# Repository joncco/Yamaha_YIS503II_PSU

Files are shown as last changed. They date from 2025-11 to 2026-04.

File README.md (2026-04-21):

# Universal Vintage Computer Power Supply
Idea for a "universal" power supply, either internal external, for different systems that require multiple input voltages (like 8080-based systems, or the BBC Model B).<br>

It's nothing groundbreaking, unique or even clever - it just uses off-the-shelf integrated components to generate the additional voltages.<br>

Expects regulated +12VDC input (rated at ≥5A).<br>

Passes through the +12VDC (≥400mA depending on input supply) and additionally outputs:
- Regulated +5VDC (max. 4A)
- Regulated -12VDC (max. 80mA)
- Regulated -5VDC (max. 500mA)

If the additional voltages are not required then they can be excluded from the build.<br>

Prevents reverse-polarity source input with a MOSFET (can be excluded if not required).<br>

The PCB measures 70x50mm and has M3 mounting holes in the corners (offset 42 & 62mm).<br>

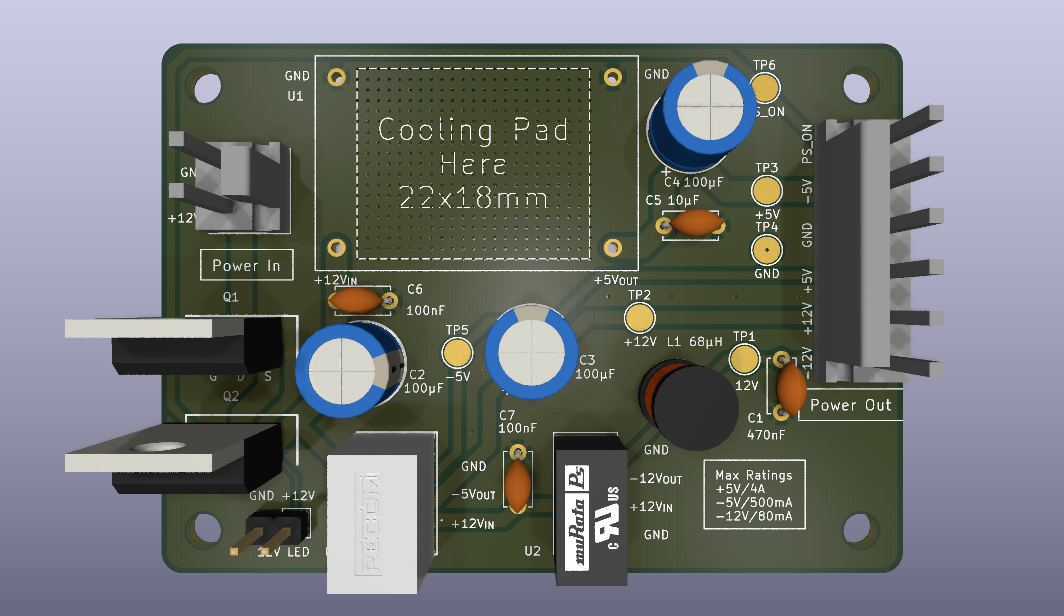
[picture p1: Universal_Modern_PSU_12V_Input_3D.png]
3D image of PCB


## [Data Sheets](/Datasheets)
Relevant data sheets to save you hunting around for the parts or trying to figure out replacements.

## [KiCad & Fabrication Files](/Universal_Modern_PSU_12V_Input)
KiCad 10 design files plus fabrication (Gerber) files

## Status
21-Nov-2025: Still tweaking the design before getting test boards made - current design should work but would like to improve further if possible

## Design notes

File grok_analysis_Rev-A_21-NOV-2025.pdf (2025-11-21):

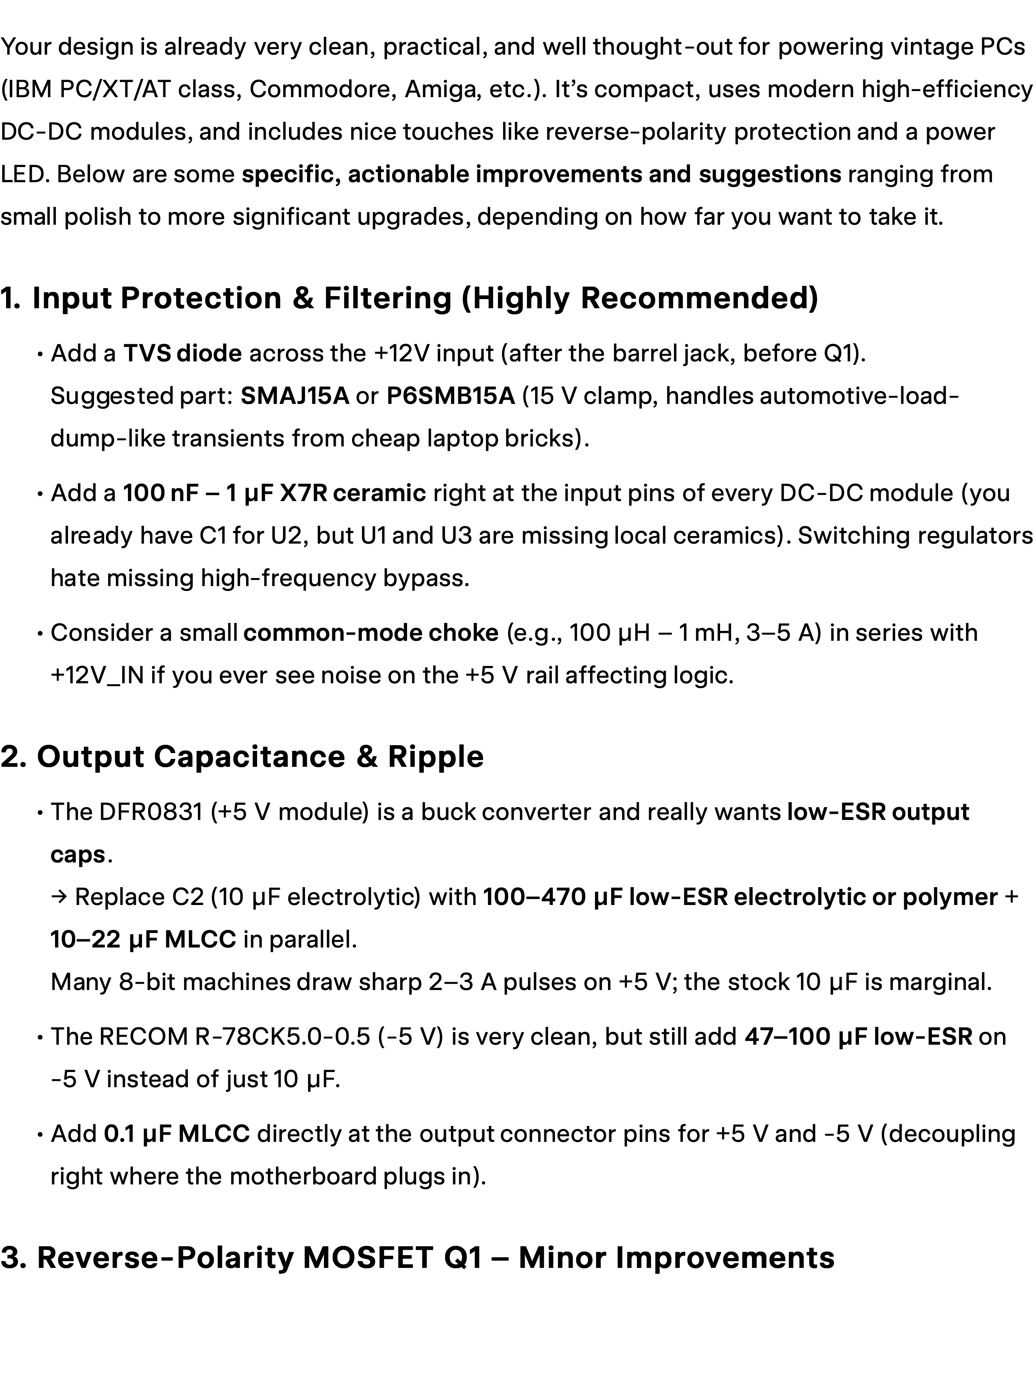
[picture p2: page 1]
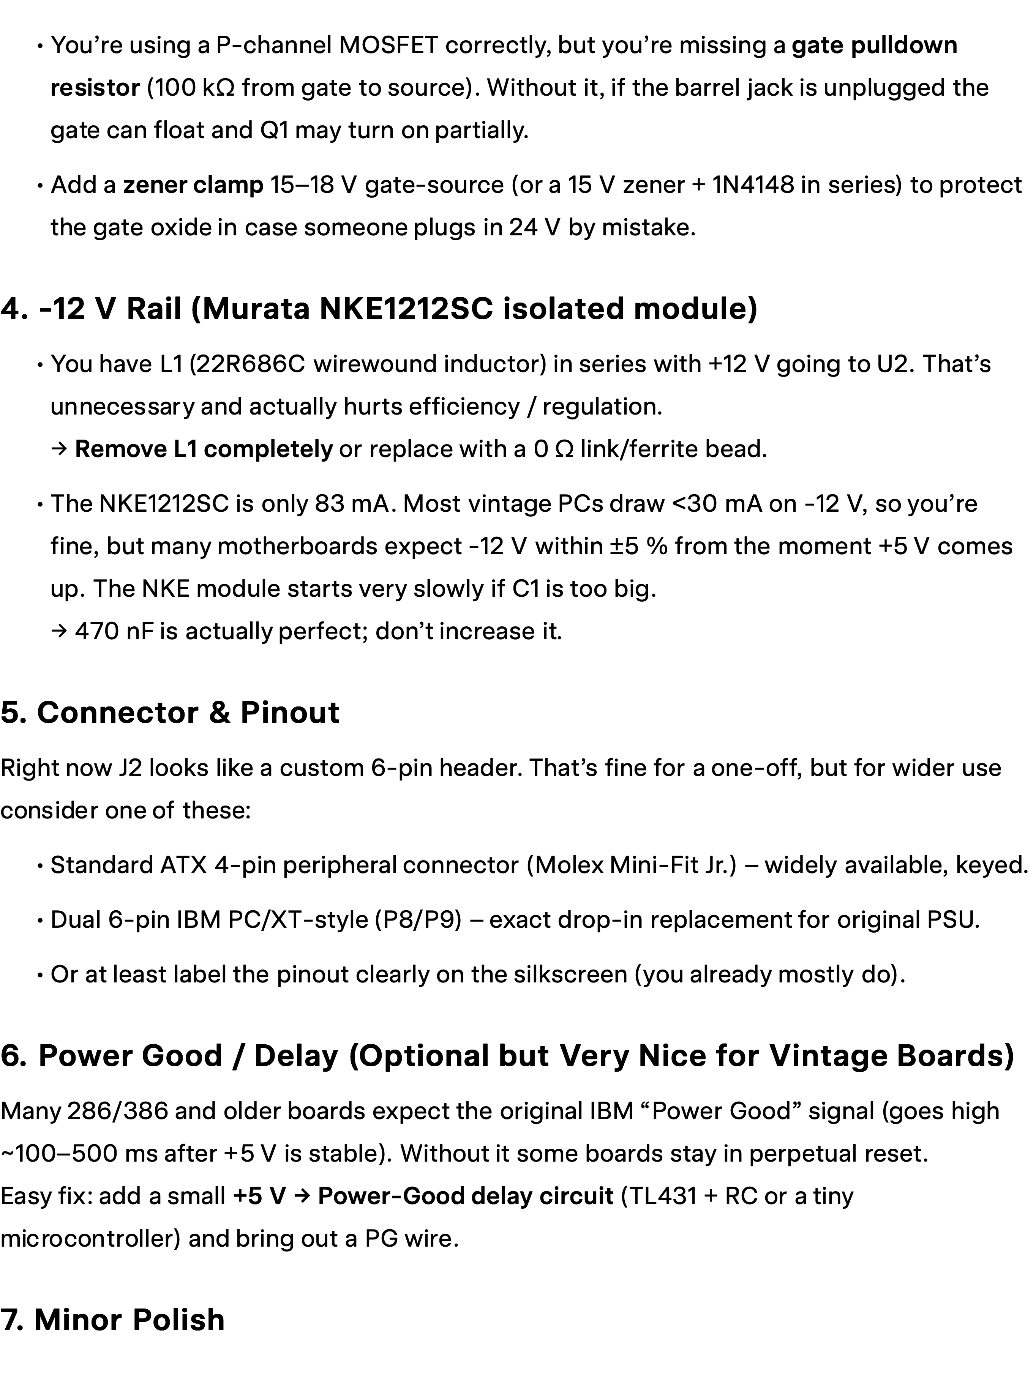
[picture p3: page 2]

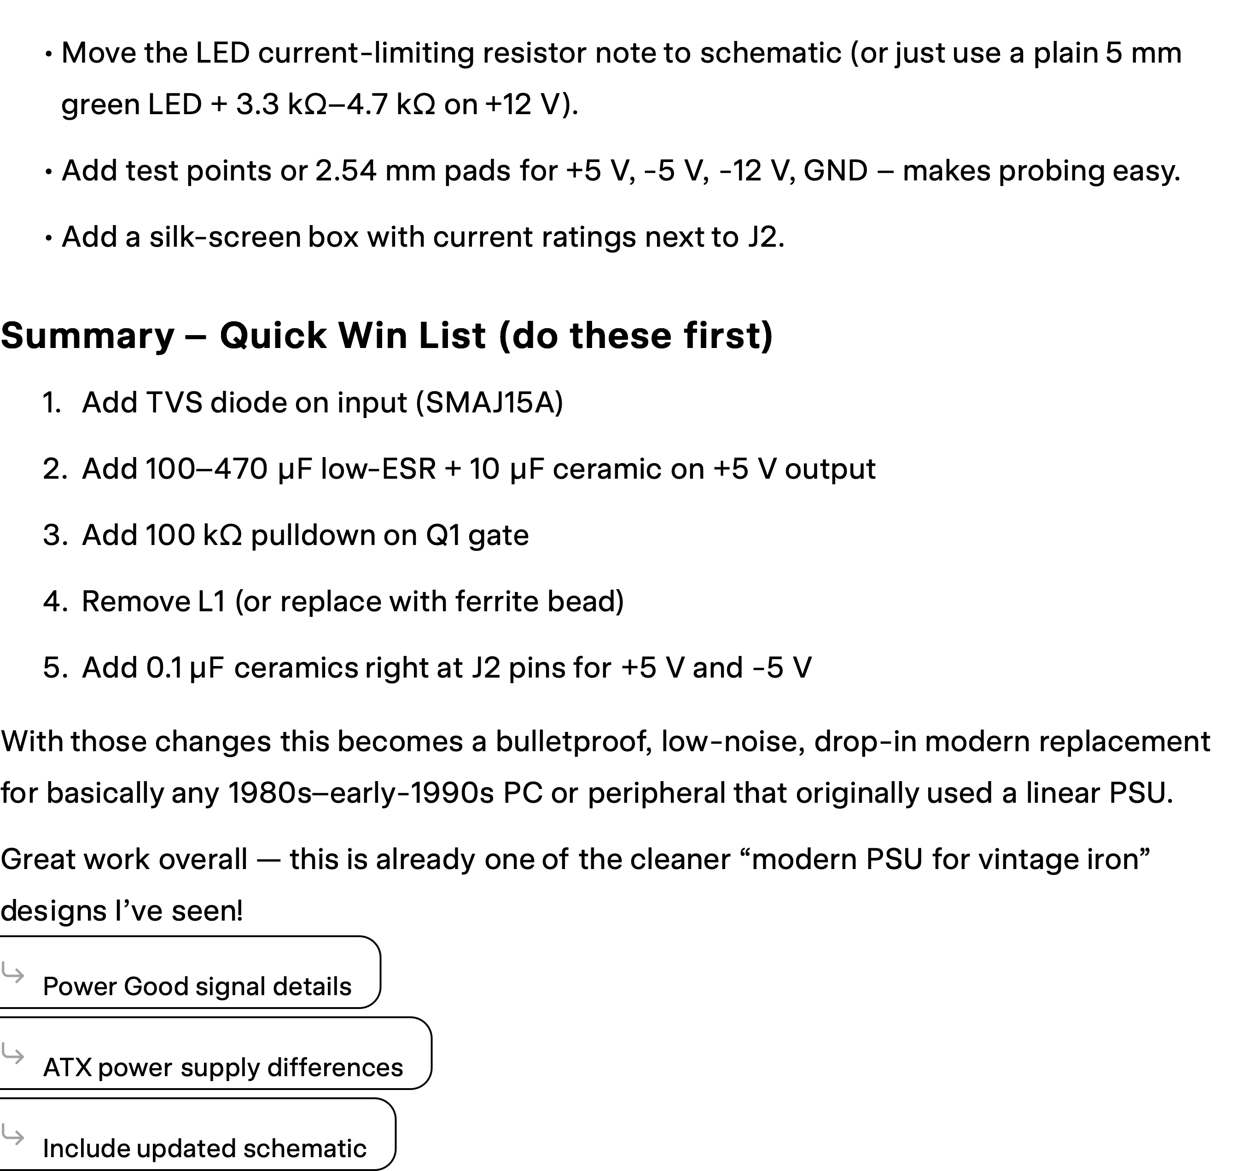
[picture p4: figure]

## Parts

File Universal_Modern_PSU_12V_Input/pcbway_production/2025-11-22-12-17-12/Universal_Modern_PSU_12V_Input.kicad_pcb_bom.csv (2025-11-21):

Designator | Quantity | Value | Footprint | Package | MPN | DNP | Mount_Type | Description | Sim.Pins | Height | Mouser Part Number | Mouser Price/Stock | Manufacturer_Name
C1 | 1 | 470nF | C_Disc_D5.0mm_W2.5mm_P5.00mm |  |  |  | tht | Unpolarized capacitor
C2, C3, C4 | 3 | 100µF | CP_Radial_D8.0mm_P5.00mm |  |  |  | tht | Polarized capacitor
C5 | 1 | 10µF | C_Disc_D5.0mm_W2.5mm_P5.00mm |  |  |  | tht | Unpolarized capacitor
C6, C7 | 2 | 100nF | C_Disc_D5.0mm_W2.5mm_P5.00mm |  |  |  | tht | Unpolarized capacitor
D1 | 1 | On | PinHeader_1x02_P2.54mm_Vertical |  |  |  | tht | Light emitting diode | 1=K 2=A
J1 | 1 | +12VDC Input | 6404452 |  |  |  | tht | DC Barrel Jack
J2 | 1 | Power Output | 640445-5 |  |  |  | tht | Generic connector, single row, 01x05, script generated (kicad-library-utils/schlib/autogen/connector/)
L1 | 1 | 68µH | 22R683C |  |  |  | tht | Inductor
Q1 | 1 | SUP53P06-20-E3 | TO254P465X1028X1931-3P |  | SUP53P06-20-E3 |  | tht | VISHAY - SUP53P06-20-E3 - MOSFET, P, TO-220 |  | 4.65 | 781-SUP53P06-20-E3 | https://www.mouser.co.uk/ProductDetail/Vishay-Semiconductors/SUP53P06-20-E3?qs=ru2xu5lizsADXHLEpSNjJA%3D%3D | Vishay
TP1 | 1 | -12V | TestPoint_Pad_D2.5mm |  |  |  | tht | test point
TP2 | 1 | +12V | TestPoint_Pad_D2.5mm |  |  |  | tht | test point
TP3 | 1 | +5V | TestPoint_Pad_D2.5mm |  |  |  | tht | test point
TP4 | 1 | GND | TestPoint_Pad_D2.5mm |  |  |  | tht | test point
TP5 | 1 | -5V | TestPoint_Pad_D2.5mm |  |  |  | tht | test point
U1 | 1 | DFR0831 | DFR0831 |  |  |  | tht | DFRobot DC-DC Buck Converter
U2 | 1 | NKE1212SC | NKE1212SC |  | NKE1212SC |  | tht | Murata Power Solutions NKE 1W Isolated DC-DC Converter Through Hole, Voltage in 10.8 13.2 V dc, Voltage out |  | 7.71 |  |  | Murata Electronics
U3 | 1 | R-78CK5.0-0.5 | R78CK5005 |  | R-78CK5.0-0.5 |  | tht | 0.5A DC/DC-Converter \'INNOLINE\' SIP3 reg |  | 10.7 |  |  | RECOM Power

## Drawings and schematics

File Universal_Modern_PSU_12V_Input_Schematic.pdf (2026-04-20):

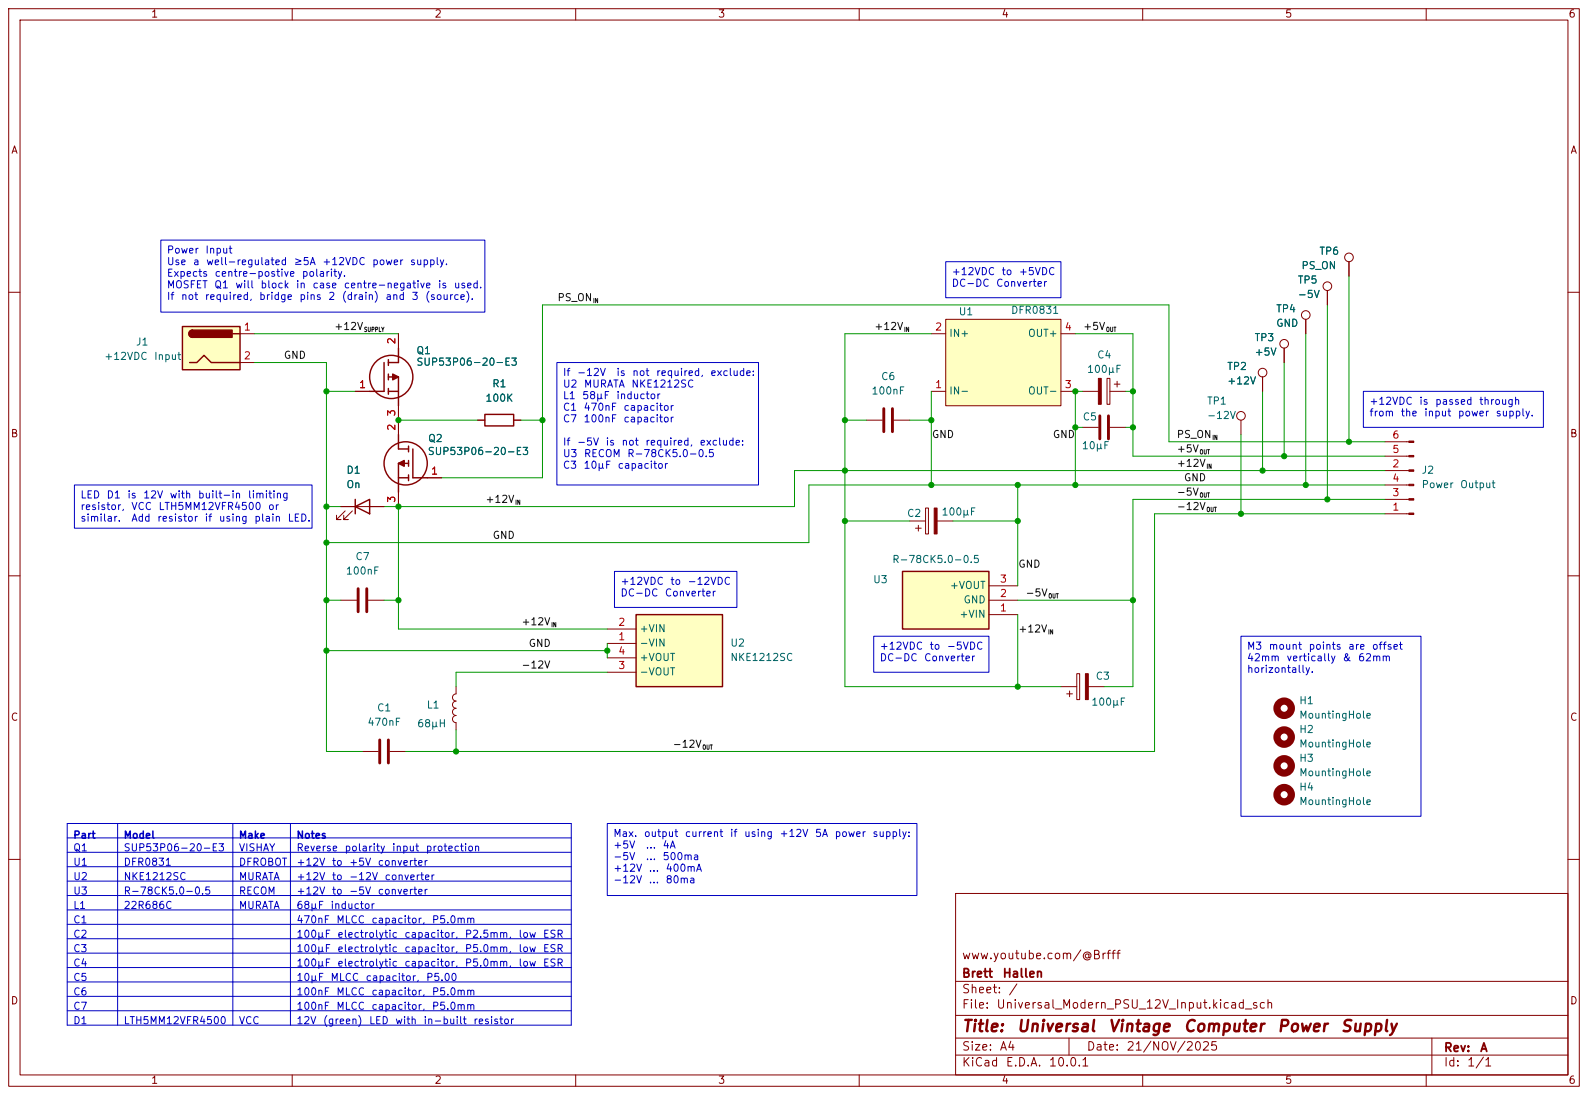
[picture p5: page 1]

DC-DC Converter Power Input Use a well-regulated ≥5A +12VDC power supply.

Expects centre-postive polarity. MOSFET Q1 will block in case centre-negative is used.

from the input power supply. +12VDC to +5VDC

horizontally. LED D1 is 12V with built-in limiting

DC-DC Converter +12VDC to -12VDC

C2 | 100µF electrolytic capacitor, P2.5mm, low ESR
C3 | 100µF electrolytic capacitor, P5.0mm, low ESR
C4 | 100µF electrolytic capacitor, P5.0mm, low ESR
C5 | 10µF MLCC capacitor, 100nF MLCC capacitor, P5.00 C6 P5.0mm

www.youtube.com/@Brfff
Brett Hallen
Sheet: /
File: Universal_Modern_PSU_12V_Input.kicad_sch
Title: Universal Vintage Computer Power Supply

C7 | 100nF MLCC capacitor, P5.0mm

Size: A4 | Rev: A
KiCad E.D.A. 10.0.1 | Id: 1/1

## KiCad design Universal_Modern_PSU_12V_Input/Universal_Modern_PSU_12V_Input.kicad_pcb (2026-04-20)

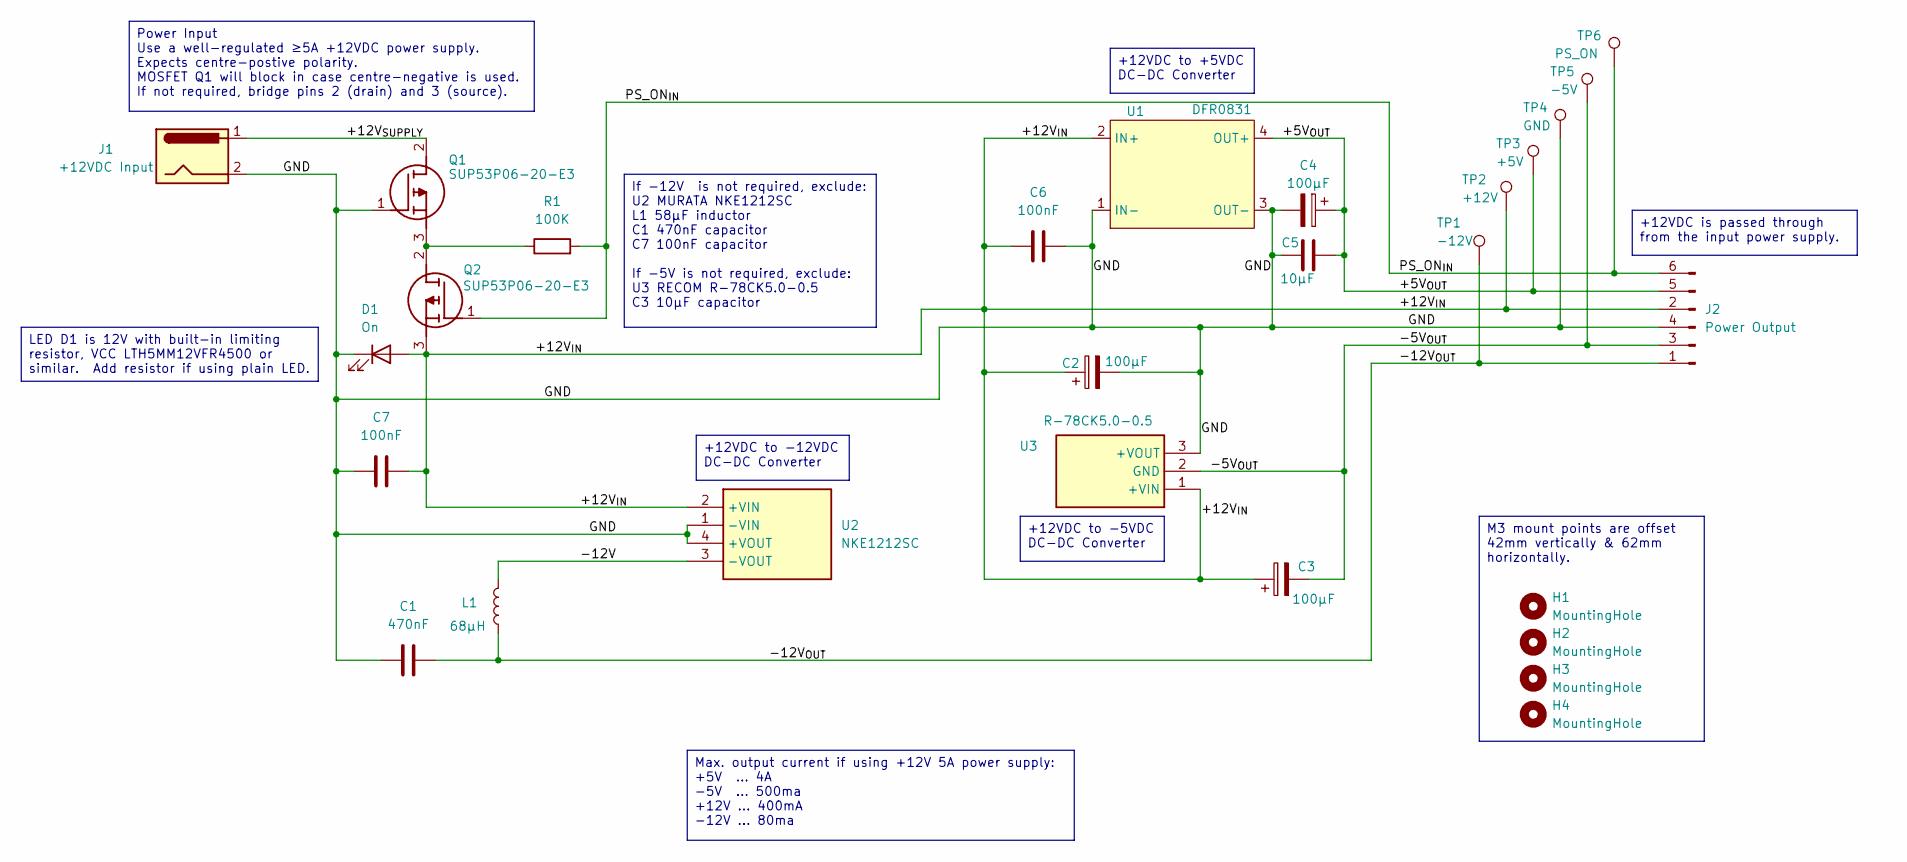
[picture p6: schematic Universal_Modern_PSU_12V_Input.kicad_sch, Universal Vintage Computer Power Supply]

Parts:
C1: 470nF; C_Disc_D5.0mm_W2.5mm_P5.00mm
C2, C3, C4: 100µF; CP_Radial_D8.0mm_P5.00mm
C5: 10µF; C_Disc_D5.0mm_W2.5mm_P5.00mm
C6, C7: 100nF; C_Disc_D5.0mm_W2.5mm_P5.00mm
D1: On; PinHeader_1x02_P2.54mm_Vertical
H1, H2, H3, H4: MountingHole; MountingHole_3.2mm_M3
J1: +12VDC Input; 6404452
J2: Power Output; 640445-6
L1: 68µH; 22R683C
Q1, Q2: SUP53P06-20-E3; TO254P465X1028X1931-3P; Mouser Part Number 781-SUP53P06-20-E3
R1: 100K
TP1: -12V; TestPoint_Pad_D2.5mm
TP2: +12V; TestPoint_Pad_D2.5mm
TP3: +5V; TestPoint_Pad_D2.5mm
TP4: GND; TestPoint_Pad_D2.5mm
TP5: -5V; TestPoint_Pad_D2.5mm
TP6: PS_ON; TestPoint_Pad_D2.5mm
U1: DFR0831
U2: NKE1212SC; Manufacturer_Part_Number NKE1212SC
U3: R-78CK5.0-0.5; R78CK5005; Manufacturer_Part_Number R-78CK5.0-0.5

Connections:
/+5V_{OUT}: C4.1, C5.2, J2.5, TP3.1 (1_1), U1.4 (OUT+)
/+12V_{IN}: C2.1, C3.1, C6.1, C7.2, D1.2 (A), J2.2, Q2.3 (S), TP2.1 (1_1), U1.2 (IN+), U2.2 (+VIN), U3.1 (+VIN)
/+12V_{SUPPLY}: J1.1, Q1.2 (D)
/-5V_{OUT}: C3.2, J2.3, TP5.1 (1_1), U3.2 (GND)
/-12V: L1.2, U2.3 (-VOUT)
/-12V_{OUT}: C1.2, J2.1, L1.1, TP1.1 (1_1)
/GND: C1.1, C2.2, C4.2, C5.1, C6.2, C7.1, D1.1 (K), J1.2, J2.4, Q1.1 (G), TP4.1 (1_1), U1.1 (IN-), U1.3 (OUT-), U2.1 (-VIN), U2.4 (+VOUT), U3.3 (+VOUT)
/PS_ON_{IN}: J2.6, Q2.1 (G), R1.2, TP6.1 (1_1)
unnamed: Q1.3 (S), Q2.2 (D), R1.1

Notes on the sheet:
If -12V is not required, exclude: U2 MURATA NKE1212SC L1 58µF inductor C1 470nF capacitor C7 100nF capacitor If -5V is not required, exclude: U3 RECOM R-78CK5.0-0.5 C3 10µF capacitor
+12VDC to -12VDC DC-DC Converter
Max. output current if using +12V 5A power supply: +5V ... 4A -5V ... 500ma +12V ... 400mA -12V ... 80ma
Power Input Use a well-regulated ≥5A +12VDC power supply. Expects centre-postive polarity. MOSFET Q1 will block in case centre-negative is used. If not required, bridge pins 2 (drain) and 3 (source).
LED D1 is 12V with built-in limiting resistor, VCC LTH5MM12VFR4500 or similar. Add resistor if using plain LED.
M3 mount points are offset 42mm vertically & 62mm horizontally.
+12VDC to +5VDC DC-DC Converter
+12VDC is passed through from the input power supply.
+12VDC to -5VDC DC-DC Converter

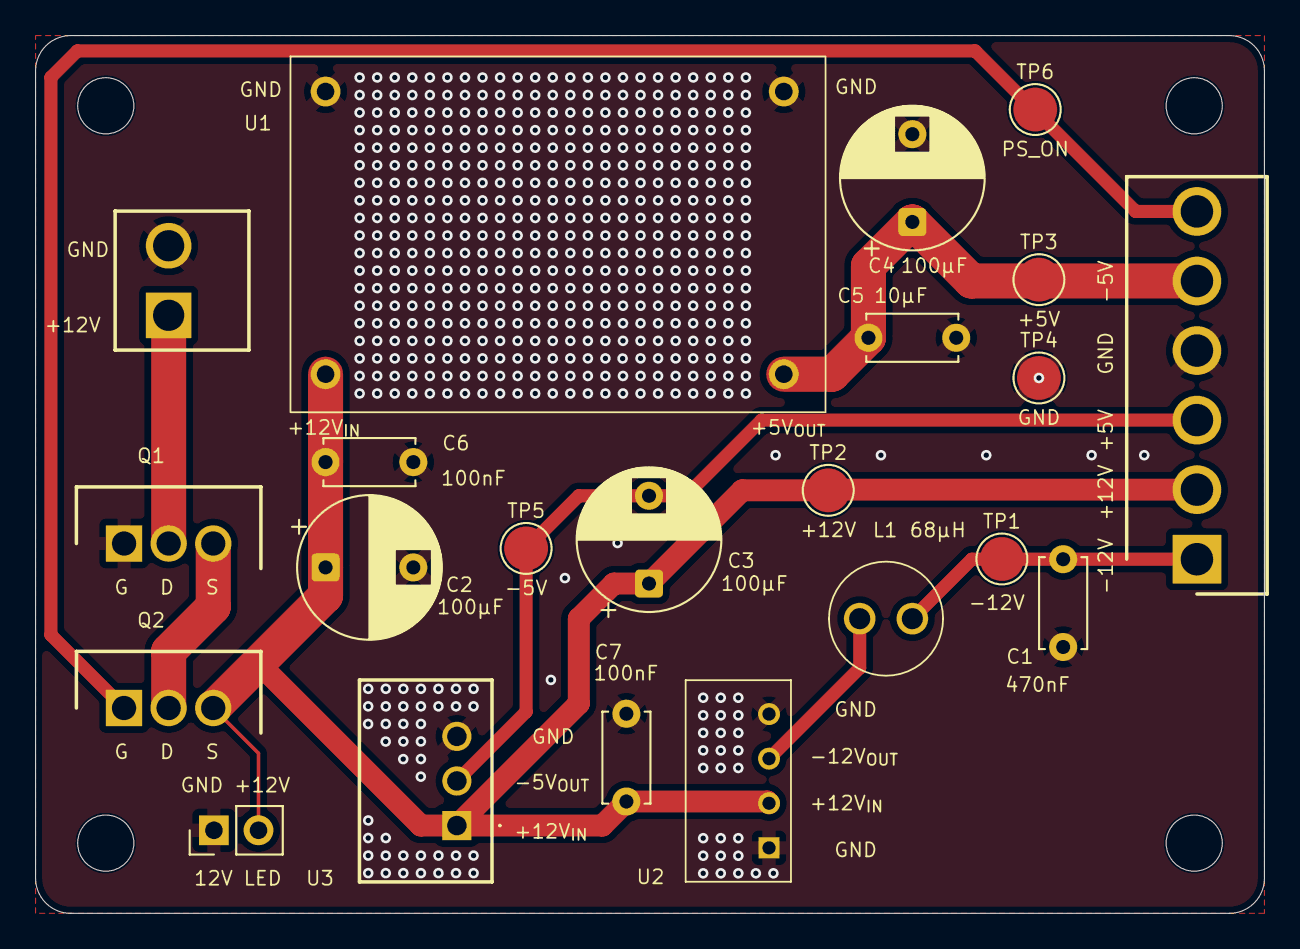
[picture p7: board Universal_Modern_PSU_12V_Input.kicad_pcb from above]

Board: 2 copper layers, 70.0 x 50.0 mm, 26 parts (0 on the bottom side), 9 nets.

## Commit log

2025-11-21 Minor updates
    [Universal_Modern_PSU.kicad_pcb, Universal_Modern_PSU.kicad_pcb_bom.csv, Universal_Modern_PSU.kicad_pcb_positions.csv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]
2025-11-21 Added additional capacitors
    [Universal_Modern_PSU.kicad_pcb, Universal_Modern_PSU.kicad_pcb_bom.csv, Universal_Modern_PSU.kicad_pcb_positions.csv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]
2025-11-21 Added mount point offsets to schematic
    [Universal_Modern_PSU.kicad_sch]
2025-11-21 Additional information on schematic
    [Universal_Modern_PSU.kicad_sch]
2025-11-21 Thickened +5V & +12V tracks
    [Universal_Modern_PSU_12V_Input.kicad_pcb, Universal_Modern_PSU_12V_Input.kicad_pcb_bom.csv, Universal_Modern_PSU_12V_Input.kicad_pcb_positions.csv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]
2025-11-21 Additional vias for heat conduction
    [Universal_Modern_PSU_12V_Input.kicad_pcb, Universal_Modern_PSU_12V_Input.kicad_pcb_bom.csv, Universal_Modern_PSU_12V_Input.kicad_pcb_positions.csv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]
2025-11-21 Minor PCB & schematic changes
    [Universal_Modern_PSU_12V_Input.kicad_pcb, Universal_Modern_PSU_12V_Input.kicad_pcb_bom.csv, Universal_Modern_PSU_12V_Input.kicad_pcb_positions.csv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]
2025-11-22 Further refinements to PCB layout
    [Universal_Modern_PSU_12V_Input.kicad_pcb, Universal_Modern_PSU_12V_Input.kicad_pcb_bom.csv, Universal_Modern_PSU_12V_Input.kicad_pcb_positions.csv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]
2026-04-17 Add PS_ON soft-on pin
    [Universal_Modern_PSU_12V_Input.kicad_sch]
2026-04-17 Update schematic pdf
2026-04-17 Add original Q1 back.
    [Universal_Modern_PSU_12V_Input.kicad_sch]
2026-04-17 Remove extra wire in Q1
    [Universal_Modern_PSU_12V_Input.kicad_sch]
2026-04-17 Add net labels for PS_ON
    [Universal_Modern_PSU_12V_Input.kicad_sch]
2026-04-20 Add footprint for connector
2026-04-20 Fix pin order of output header
    [Universal_Modern_PSU_12V_Input.kicad_sch]
2026-04-20 Implement schematic changes to PCB
    [Universal_Modern_PSU_12V_Input.kicad_pcb]
2026-04-20 Fix header pin order
2026-04-20 Update KiCad version in README
    Updated KiCad version from 9 to 10 in the README.
2026-04-21 Update KiCad & Fabrication Files link in README
2026-04-21 Generate interactive BOM
